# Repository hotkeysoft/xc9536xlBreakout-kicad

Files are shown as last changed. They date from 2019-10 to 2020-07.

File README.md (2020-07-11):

# XC9536XL Breakout Board

Rev A October 2019

XC9536XL CPLD Features
============
- 5 ns pin-to-pin logic delays
- System frequency up to 178 MHz
- 36 macrocells with 800 usable gates
- 5V tolerant I/O pins (accept 5 V, 3.3V, and 2.5V signals)
- 3.3V or 2.5V output capability

[datasheet](https://www.xilinx.com/support/documentation/data_sheets/ds058.pdf)

Breakout Board Features
============
- JTAG Programming Header
- 5V->3.3V Voltage Regulator to power XC9536XL
- XC9536XL is 5V tolerant and, with a 3.3V output, is compatible with in 5V TTL projects.

Images
============
|Front | Back |
|---|---|
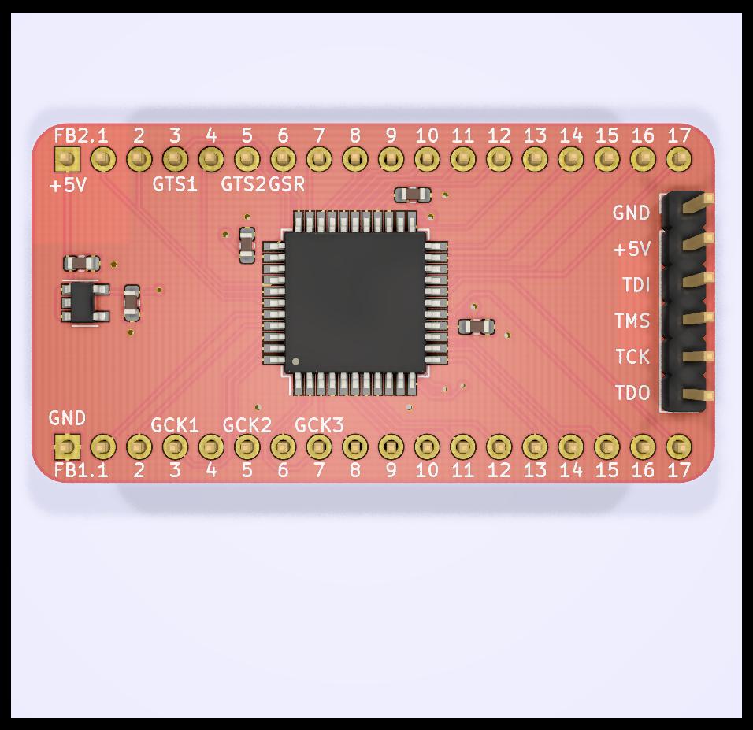
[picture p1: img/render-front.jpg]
Render Front
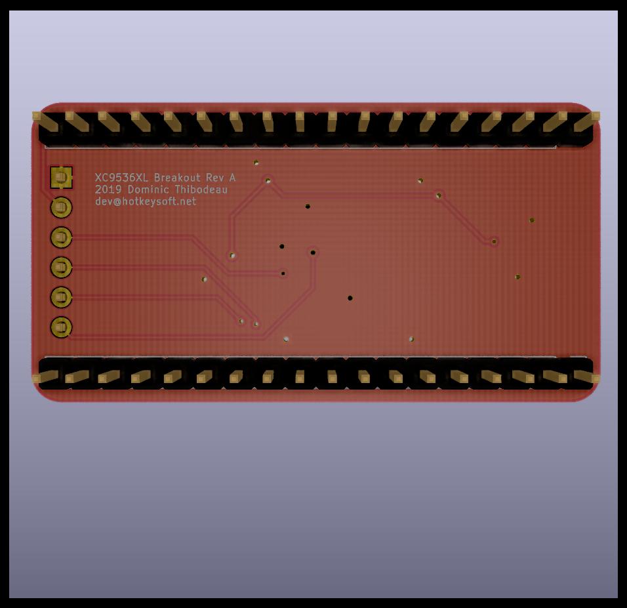
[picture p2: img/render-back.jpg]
Render Back
|||

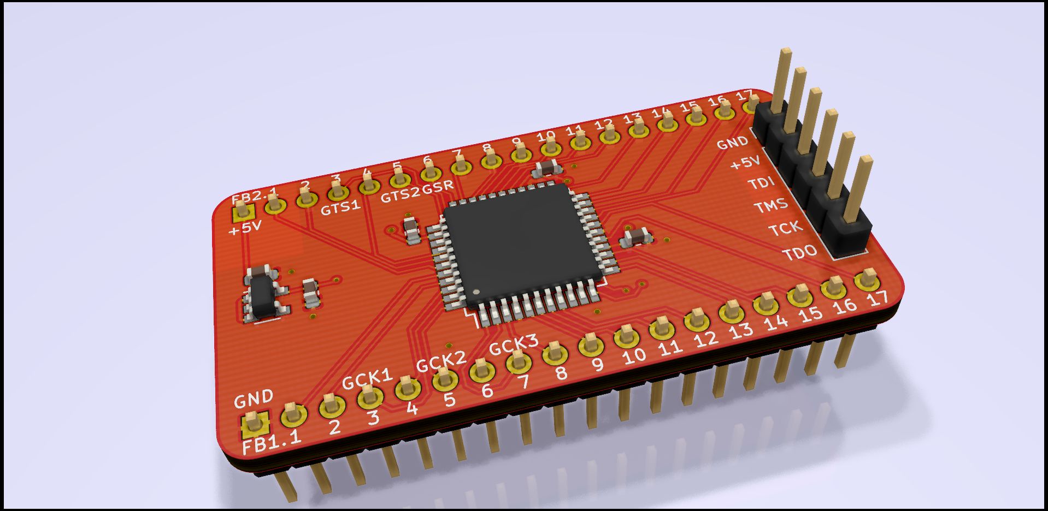
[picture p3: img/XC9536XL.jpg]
Render


### Schematics (pdf)
- [Complete schematics](./img/schema.pdf)

### PCB Images (svg)
- [Top](./img/pcb-front.svg)
- [Bottom](./img/pcb-back.svg)

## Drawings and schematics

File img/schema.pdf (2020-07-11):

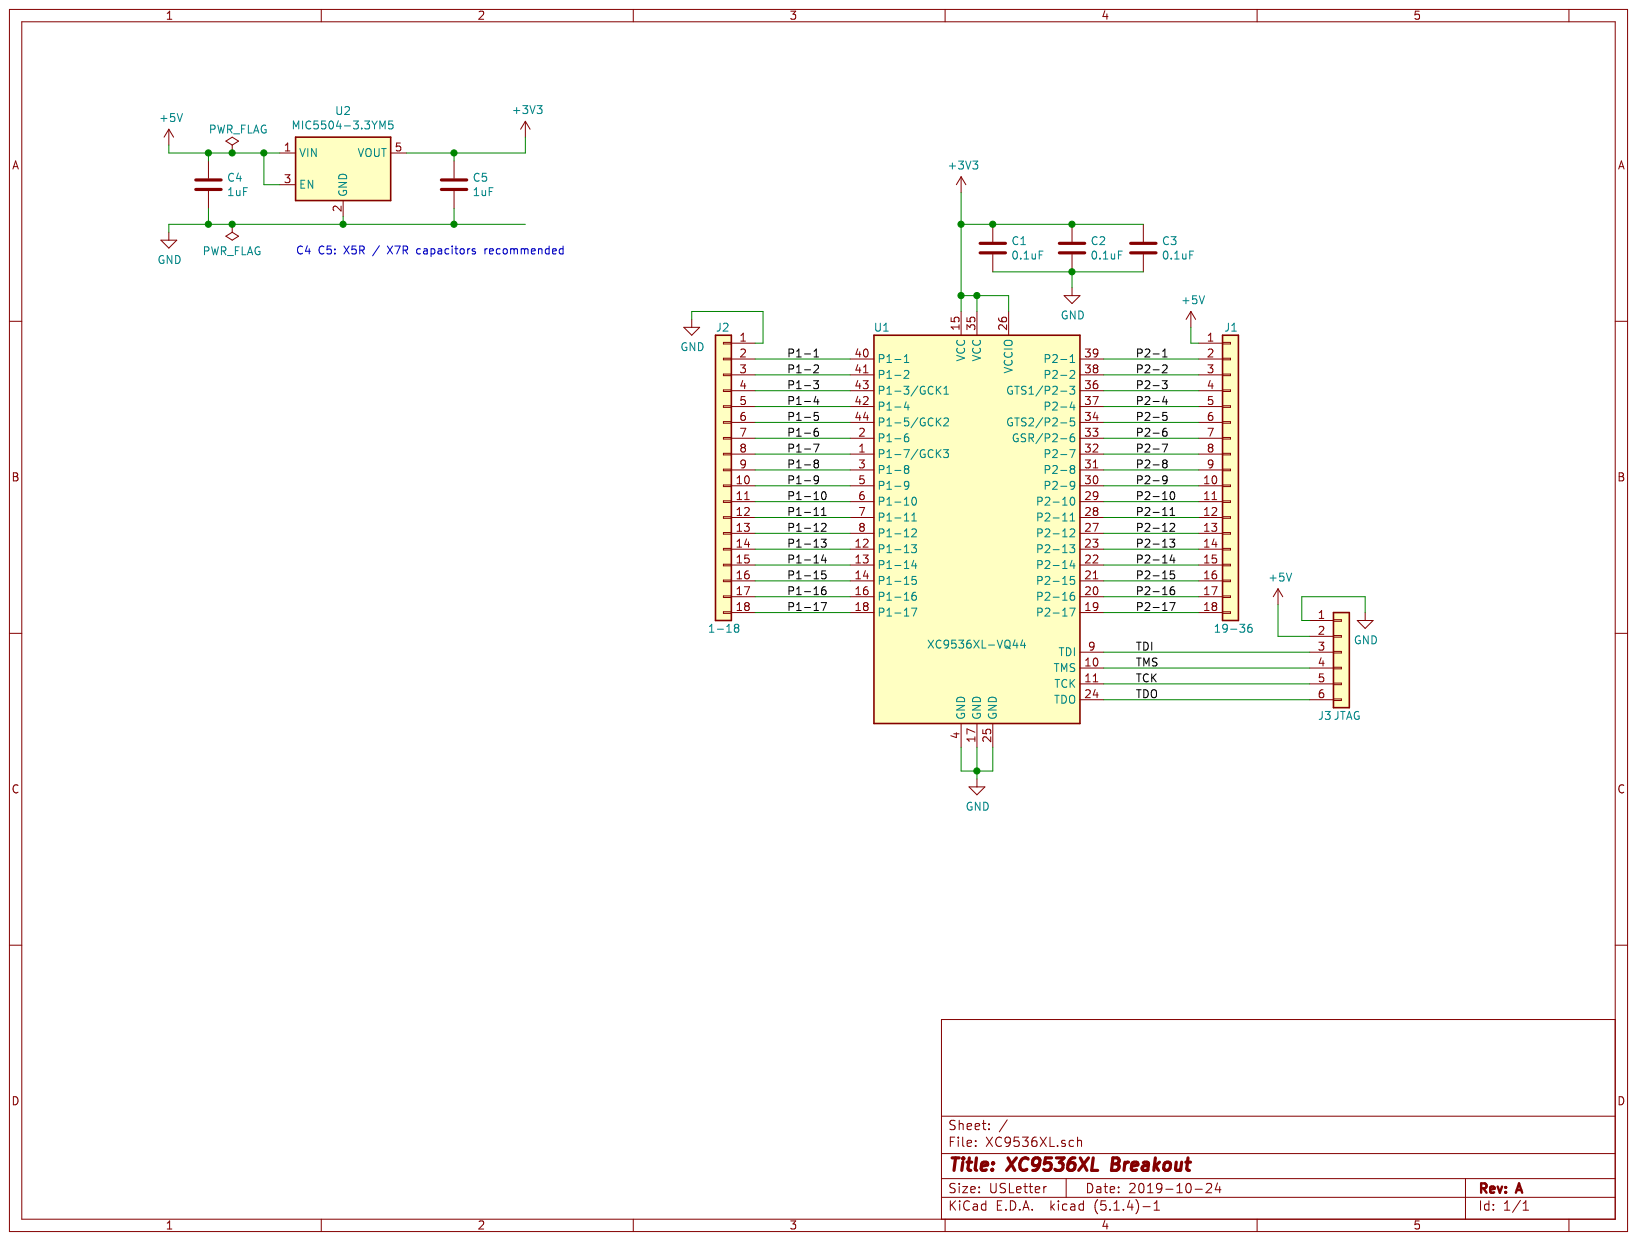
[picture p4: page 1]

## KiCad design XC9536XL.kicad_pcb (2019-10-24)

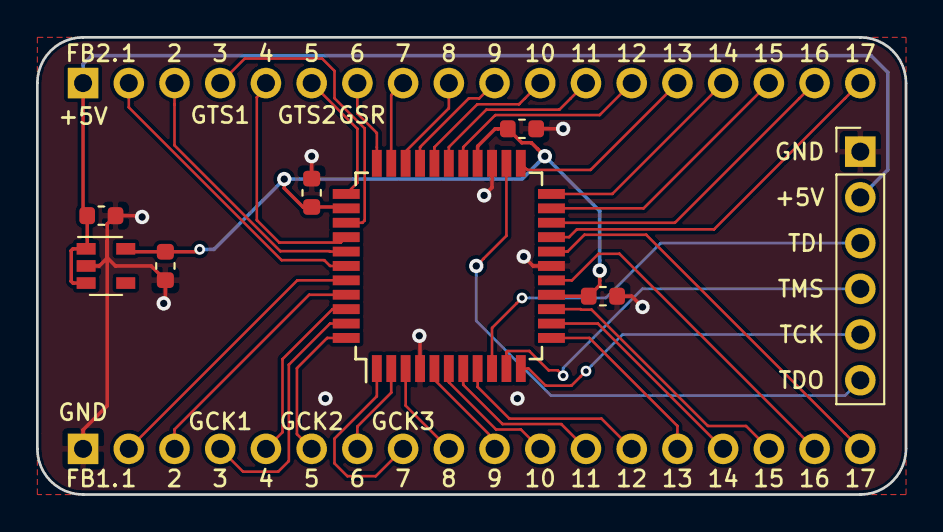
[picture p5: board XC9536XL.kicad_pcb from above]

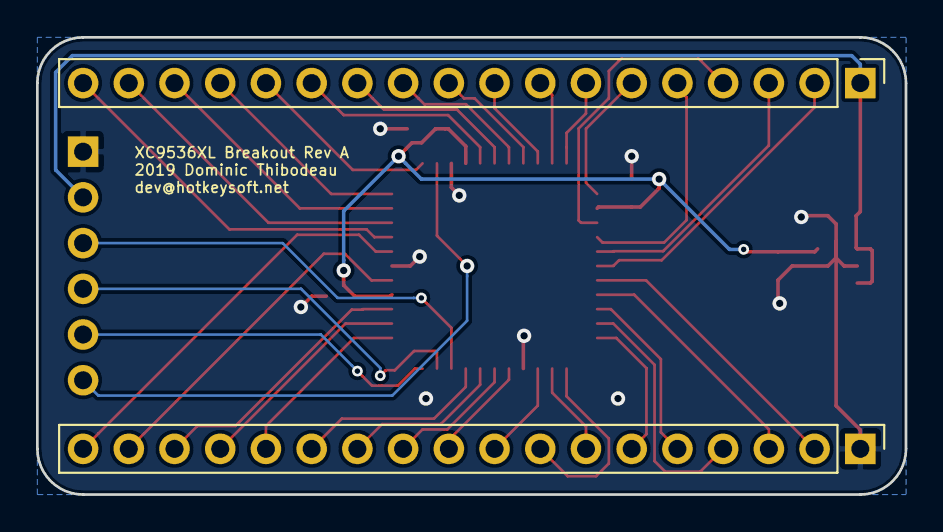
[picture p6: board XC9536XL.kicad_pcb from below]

Board: 2 copper layers, 48.3 x 25.4 mm, 10 parts (2 on the bottom side), 41 nets.

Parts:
C1, C2, C3: 0.1uF; C_0603_1608Metric
C4, C5: 1uF; C_0603_1608Metric
J1: 19-36; PinHeader_1x18_P2.54mm_Vertical
J2: 1-18; PinHeader_1x18_P2.54mm_Vertical
J3: JTAG; PinHeader_1x06_P2.54mm_Vertical
U1: XC9536XL-VQ44; TQFP-44_10x10mm_P0.8mm
U2: MIC5504-3.3YM5; SOT-23-5

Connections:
+3V3: C1.1, C2.1, C3.1, C5.1, U1.15, U1.26, U1.35, U2.5
+5V: C4.1, J1.1, J3.2, U2.1, U2.3
/P1-1: J2.2, U1.40
/P1-2: J2.3, U1.41
/P1-3: J2.4, U1.43
/P1-4: J2.5, U1.42
/P1-5: J2.6, U1.44
/P1-6: J2.7, U1.2
/P1-7: J2.8, U1.1
/P1-8: J2.9, U1.3
/P1-9: J2.10, U1.5
/P1-10: J2.11, U1.6
/P1-11: J2.12, U1.7
/P1-12: J2.13, U1.8
/P1-13: J2.14, U1.12
/P1-14: J2.15, U1.13
/P1-15: J2.16, U1.14
/P1-16: J2.17, U1.16
/P1-17: J2.18, U1.18
/P2-1: J1.2, U1.39
/P2-2: J1.3, U1.38
/P2-3: J1.4, U1.36
/P2-4: J1.5, U1.37
/P2-5: J1.6, U1.34
/P2-6: J1.7, U1.33
/P2-7: J1.8, U1.32
/P2-8: J1.9, U1.31
/P2-9: J1.10, U1.30
/P2-10: J1.11, U1.29
/P2-11: J1.12, U1.28
/P2-12: J1.13, U1.27
/P2-13: J1.14, U1.23
/P2-14: J1.15, U1.22
/P2-15: J1.16, U1.21
/P2-16: J1.17, U1.20
/P2-17: J1.18, U1.19
/TCK: J3.5, U1.11
/TDI: J3.3, U1.9
/TDO: J3.6, U1.24
/TMS: J3.4, U1.10
GND: C1.2, C2.2, C3.2, C4.2, C5.2, J2.1, J3.1, U1.4, U1.17, U1.25, U2.2

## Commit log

2019-10-24 XC9536XL Breakout board
    [XC9536XL.kicad_pcb, XC9536XL.sch]
2019-10-24 Added measurements, plots
    [XC9536XL-B_Cu.gbr, XC9536XL-B_Mask.gbr, XC9536XL-B_SilkS.gbr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]
2019-10-24 lib thing
    [XC9536XL.sch]
